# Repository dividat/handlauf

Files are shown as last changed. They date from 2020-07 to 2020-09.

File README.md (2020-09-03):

# Handlauf

**PCB Design, Firmware and Driver vor the Dividat Handlauf Extension**

## PCB Design

See the `Handlauf.sch` and `Handlauf.brd` EAGLE files. The CAM output for
production can be found in the `cam.zip` file.

## Firmware

The `Handlauf.ino` is the Arduino based firmware for the built-in Arduino.
Download the "capacitive sensor" and "ewma" library from the Arduino library
manager.

## Driver

The `*.go` files make up the Go based driver for the sensor. It can be built
using the standard Go mechanisms. A compiled version for macOS is available on
the release page: https://github.com/256dpi/handlauf/releases. 

The binary provides the following options:

```
Usage of ./handlauf:
  -addr string
        WebSocket server address (default "0.0.0.0:8080")
  -debug string
        Debug server address e.g. ":1234"
  -freq int
        Sample publish frequency (default 60)
  -min-range float
        The minimum range (default 1000)
  -threshold float
        The threshold for on/off values
```

The driver contains a Web based debug interface to inspect the sensor values.
If the driver is started with the `-debug :1234` flag, the interface is
available at `http://0.0.0.0:1234`.

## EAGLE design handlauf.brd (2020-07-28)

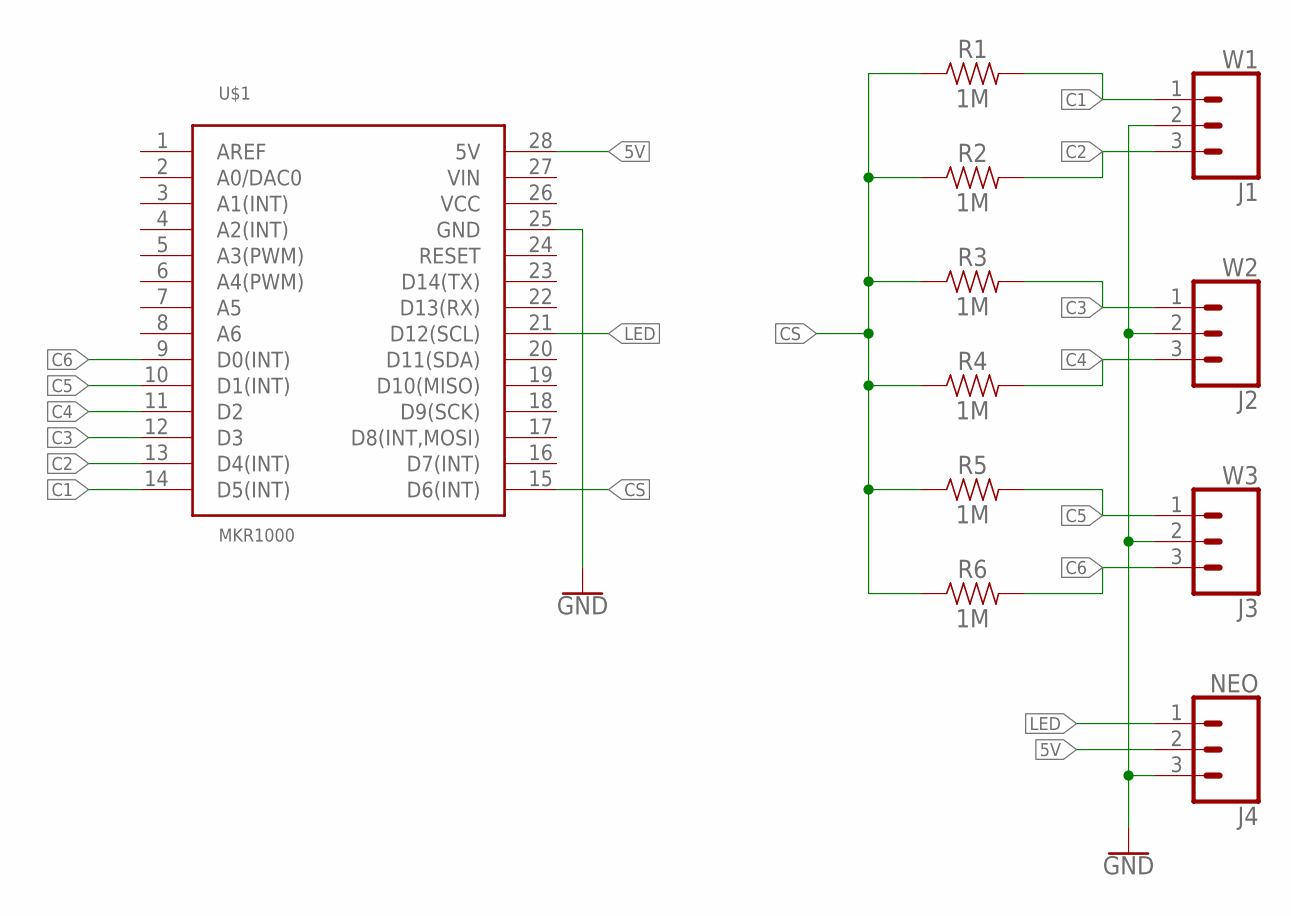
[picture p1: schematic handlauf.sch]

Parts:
J1: W1; SCREWTERMINAL-3.5MM-3
J2: W2; SCREWTERMINAL-3.5MM-3
J3: W3; SCREWTERMINAL-3.5MM-3
J4: NEO; 1X03
R1, R2, R3, R4, R5, R6: 1M; AXIAL-0.3
U$1: MKR1000; MKR1000-SOCKET

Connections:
5V: J4.2, U$1.28 (5V)
C1: J1.1, R1.P$2 (2), U$1.14 (D5(INT))
C2: J1.3, R2.P$2 (2), U$1.13 (D4(INT))
C3: J2.1, R3.P$2 (2), U$1.12 (D3)
C4: J2.3, R4.P$2 (2), U$1.11 (D2)
C5: J3.1, R5.P$2 (2), U$1.10 (D1(INT))
C6: J3.3, R6.P$2 (2), U$1.9 (D0(INT))
CS: R1.P$1 (1), R2.P$1 (1), R3.P$1 (1), R4.P$1 (1), R5.P$1 (1), R6.P$1 (1), U$1.15 (D6(INT))
GND: J1.2, J2.2, J3.2, J4.3, U$1.25 (GND)
LED: J4.1, U$1.21 (D12(SCL))

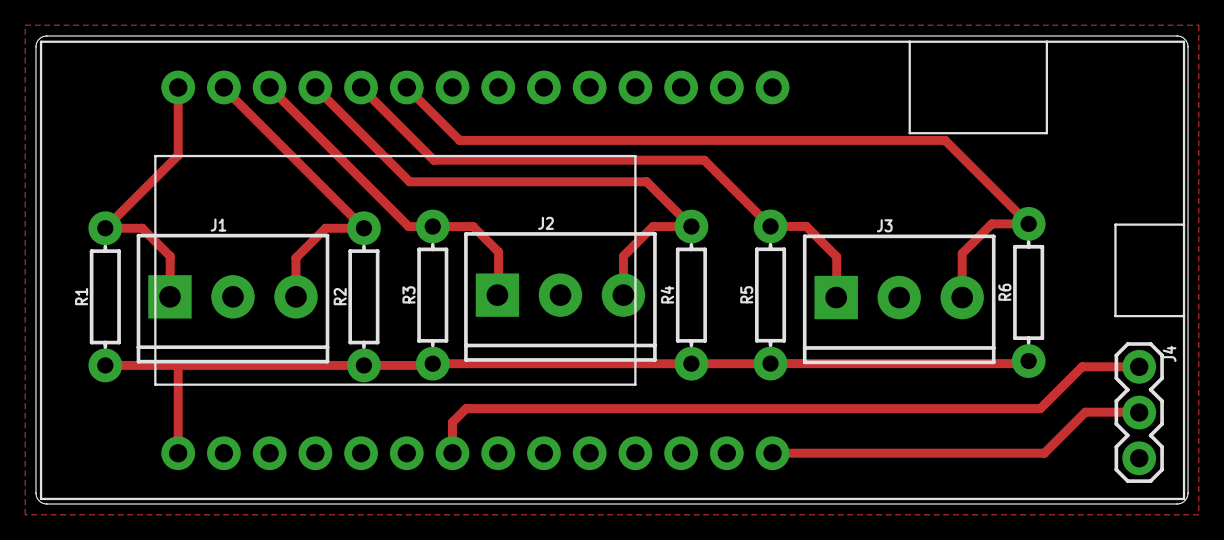
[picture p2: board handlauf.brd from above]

Board: 2 copper layers, 64.0 x 26.0 mm, 11 parts (0 on the bottom side), 10 nets.

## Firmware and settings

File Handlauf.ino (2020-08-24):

#include <CapacitiveSensor.h>
#include <Ewma.h>

#define ORIENTATION "L"

#define FILTER 0.1

#define SAMPLES 5

#define DELAY 1 // 1KHz

CapacitiveSensor s1 = CapacitiveSensor(6, 0);
CapacitiveSensor s2 = CapacitiveSensor(6, 1);
CapacitiveSensor s3 = CapacitiveSensor(6, 2);
CapacitiveSensor s4 = CapacitiveSensor(6, 3);
CapacitiveSensor s5 = CapacitiveSensor(6, 4);
CapacitiveSensor s6 = CapacitiveSensor(6, 5);

Ewma f1(FILTER);
Ewma f2(FILTER);
Ewma f3(FILTER);
Ewma f4(FILTER);
Ewma f5(FILTER);
Ewma f6(FILTER);

void setup() {
  Serial.begin(115200);

  s1.set_CS_AutocaL_Millis(2000);
  s2.set_CS_AutocaL_Millis(2000);
  s3.set_CS_AutocaL_Millis(2000);
  s4.set_CS_AutocaL_Millis(2000);
  s5.set_CS_AutocaL_Millis(2000);
  s6.set_CS_AutocaL_Millis(2000);
}

void loop() {
  float r1 = (float) s1.capacitiveSensor(SAMPLES);
  float r2 = (float) s2.capacitiveSensor(SAMPLES);
  float r3 = (float) s3.capacitiveSensor(SAMPLES);
  float r4 = (float) s4.capacitiveSensor(SAMPLES);
  float r5 = (float) s5.capacitiveSensor(SAMPLES);
  float r6 = (float) s6.capacitiveSensor(SAMPLES);
  
  float v1 = f1.filter(r1);
  float v2 = f2.filter(r2);
  float v3 = f3.filter(r3);
  float v4 = f4.filter(r4);
  float v5 = f5.filter(r5);
  float v6 = f6.filter(r6);

  Serial.print(ORIENTATION);
  Serial.print(",");
  Serial.print(v1);
  Serial.print(",");
  Serial.print(v2);
  Serial.print(",");
  Serial.print(v3);
  Serial.print(",");
  Serial.print(v4);
  Serial.print(",");
  Serial.print(v5);
  Serial.print(",");
  Serial.print(v6);
  Serial.println();

  delay(DELAY);
}

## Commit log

2020-07-21 added pcb
    [handlauf.brd, handlauf.sch]
2020-07-21 added socket.io
2020-07-28 rounded corners
    [handlauf.brd]
2020-08-18 switched to pure websockets
2020-08-24 added multi device support

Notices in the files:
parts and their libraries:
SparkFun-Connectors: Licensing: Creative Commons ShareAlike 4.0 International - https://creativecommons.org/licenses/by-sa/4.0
